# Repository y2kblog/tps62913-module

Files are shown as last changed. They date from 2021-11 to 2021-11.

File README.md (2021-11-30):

# TPS62913 低ノイズ・低リップル 可変出力降圧モジュール

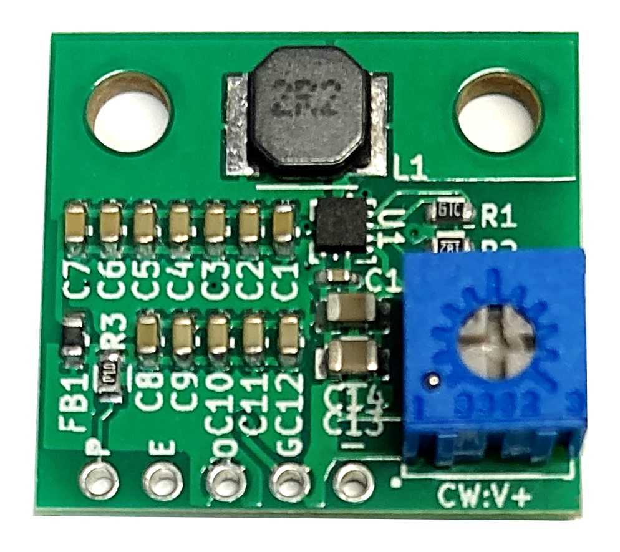
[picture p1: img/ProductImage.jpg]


## 概要

低ノイズ・低リップルの降圧型DC/DCコンバータ TPS62913 (Texas Instruments Inc.製) を搭載したモジュールです。  
低ノイズLDOに匹敵する**20µV<sub>RMS</sub>の1/fノイズ**と、IC内蔵のフェライトビーズLCフィルタ補償機能による**10µV<sub>RMS</sub>未満の低リップル**を実現しており、ノイズの影響を受けやすいアプリケーション（例：実験用精密電源、高速ADC、レーダー）の電源供給に適しています。  
また、スイッチングレギュレータのため最大3.0Aの電流を出力できます。  

### 仕様
- 入力電圧：3.0～17.0V
- 出力電圧：0.9～5.1V (基板上の半固定抵抗で調整)
- 最大出力電流：3.0A
- 1/fノイズ：20µV<sub>RMS</sub> (100Hz～100kHz)
- 電圧リップル：10µV<sub>RMS</sub>未満 (typ.)
- イネーブルピン付き
- パワー・グッドピン付き
- 出力放電機能：有効
- ソフトスタート時間：10.7ms (typ.)
- 基板サイズ：20mm × 22mm
- ピン間隔：2.54mm
<!--
- スイッチング周波数：2.2MHz (typ.)
- スペクトラム拡散変調：有効
-->

## 販売  
[スイッチサイエンス委託販売ページ](https://www.switch-science.com/catalog/7619/)  
※大量注文や在庫に関する問い合わせは[こちら](mailto:info.y2kb@gmail.com)までご連絡ください。  

## ピンアサイン
<table>
    <thead>
        <tr>
            <th>#</th>
            <th>ピン名</th>
            <th>表面シルク</th>
            <th>説明</th>
        </tr>
    </thead>
    <tbody>
        <tr>
            <td>1</td>
            <td>VIN</td>
            <td>I</td>
            <td>電源入力</td>
        </tr>
        <tr>
            <td>2</td>
            <td>GND</td>
            <td>G</td>
            <td>グラウンド（基準電位）</td>
        </tr>
        <tr>
            <td>3</td>
            <td>VOUT</td>
            <td>O</td>
            <td>電源出力</td>
        </tr>
        <tr>
            <td>4</td>
            <td>EN</td>
            <td>E</td>
            <td>イネーブル<br>デフォルトではENピンはVINピンに基板内部で接続されており、常時出力ONです。基板裏面のJP1ショートジャンパをカッター等で切断するとENピンによる出力ON/OFF制御が可能になり、ENピンに約1V以上を印加すると出力がONになります。</td>
        </tr>
        <tr>
            <td>5</td>
            <td>PG</td>
            <td>P</td>
            <td>パワー・グッド<br>VOUTがパワー・グッド閾値電圧を下回るとGNDと同等の電圧となります。出力電圧が良好な場合はVOUTと同等の電圧となります。</td>
        </tr>
    </tbody>
</table>

## 回路図  
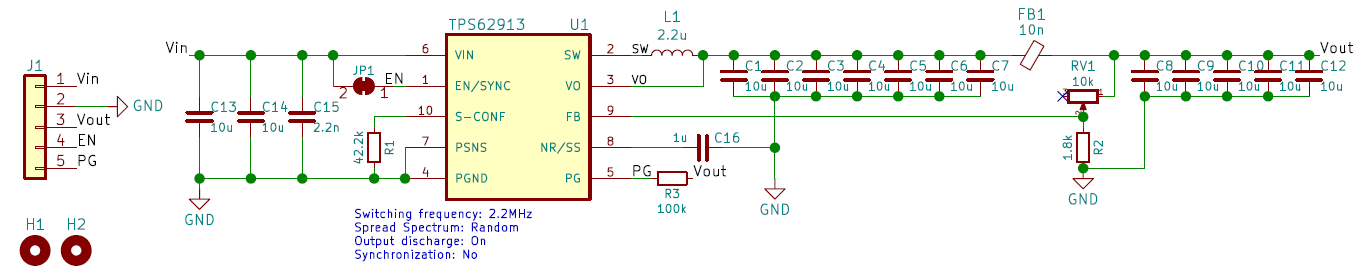
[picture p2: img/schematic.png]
  

<!--<a href="/hardware/tps62913-module.pdf">回路図(PDF)</a>  -->

## 基板寸法
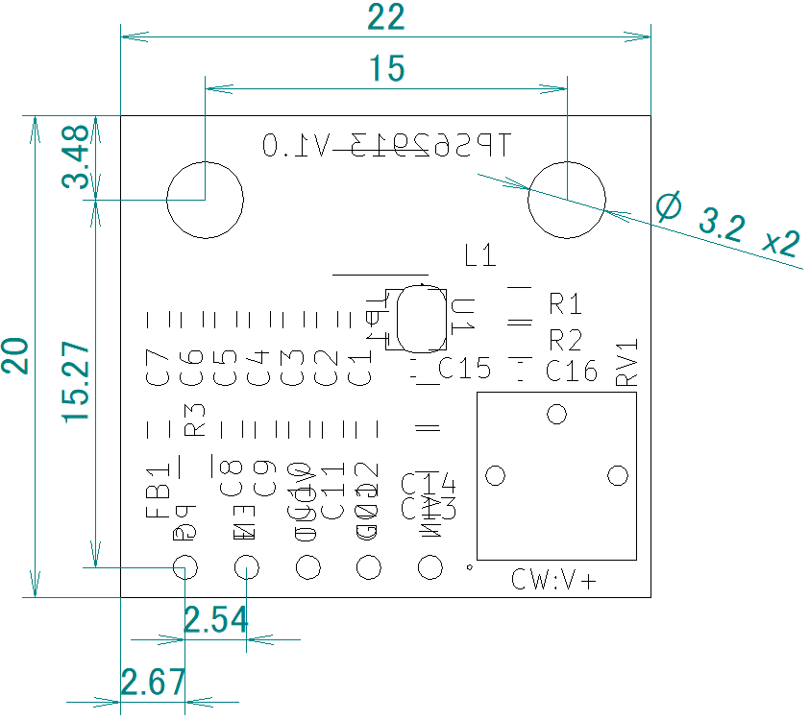
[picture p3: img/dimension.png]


## 資料
- 2Dデータ(DXF)：<a href="https://github.com/y2kblog/tps62913-module/raw/master/hardware/dxf/tps62913-module_dxf.zip" download="">tps62913-module_dxf.zip</a>  
- 3Dデータ(STEP)：<a href="https://github.com/y2kblog/tps62913-module/raw/master/hardware/step/tps62913-module_step.zip" download="">tps62913-module_step.zip</a>  
- [TPS61099xデータシート](https://www.tij.co.jp/lit/gpn/tps62913)

## License
MIT License, see `/LICENSE`.

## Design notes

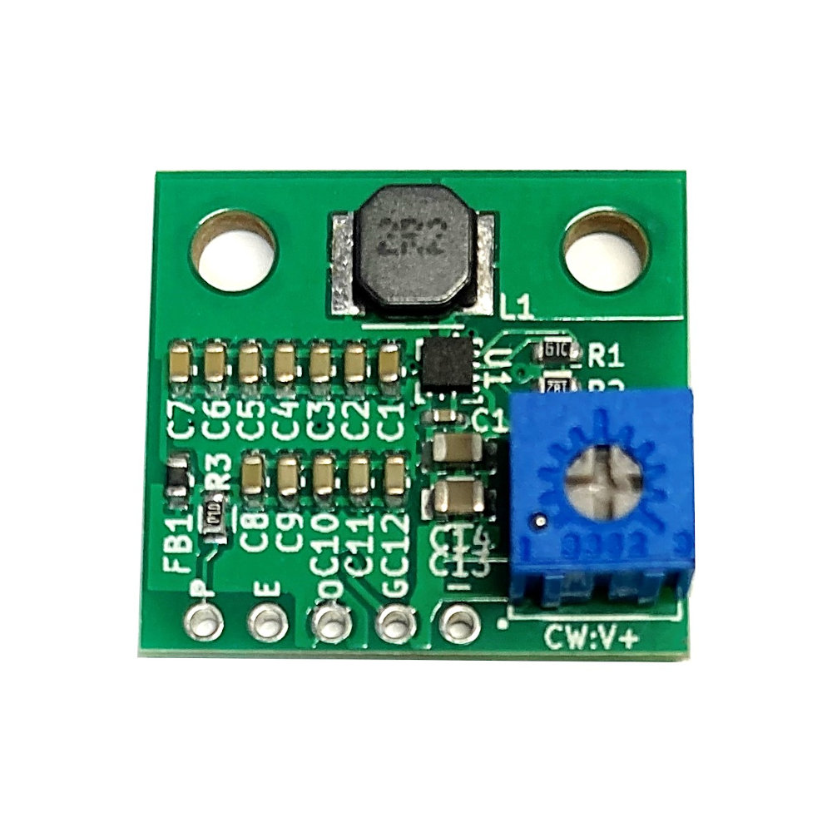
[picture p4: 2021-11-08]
img/ProductImage_1000px.jpg

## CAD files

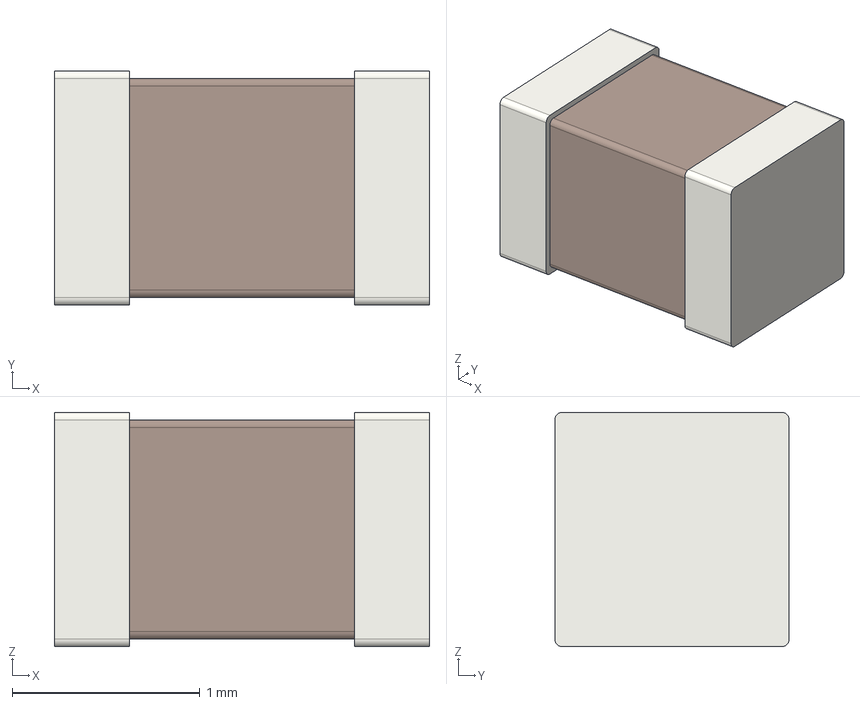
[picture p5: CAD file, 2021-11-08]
hardware/3d/C_0805_2012Metric.step
2.00 x 1.25 x 1.25 mm

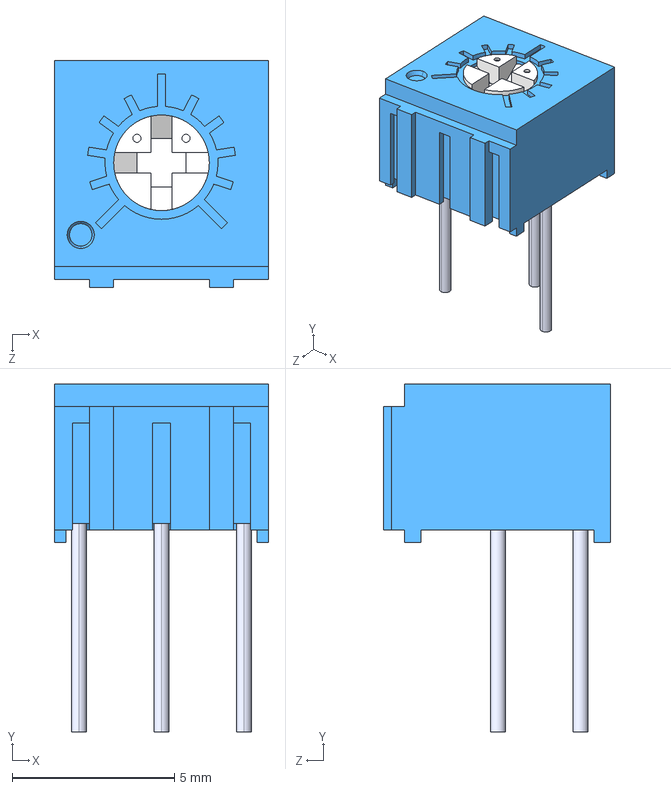
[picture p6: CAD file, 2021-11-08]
hardware/3d/3362P-1.STEP
6.60 x 10.7 x 6.99 mm

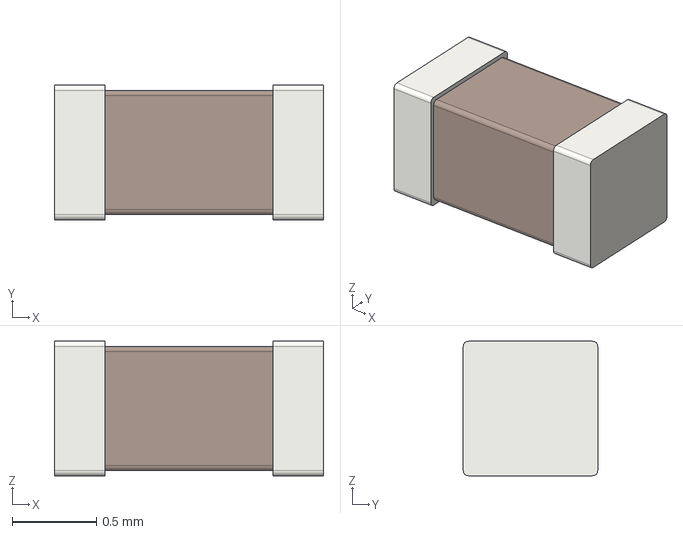
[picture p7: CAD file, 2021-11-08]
hardware/3d/C_0603_1608Metric.step
1.60 x 0.8 x 0.8 mm

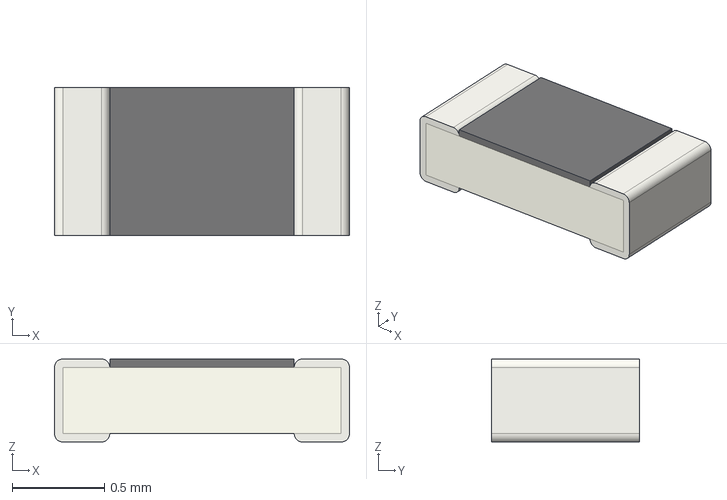
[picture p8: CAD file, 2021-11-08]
hardware/3d/R_0603_1608Metric.step
1.60 x 0.8 x 0.45 mm

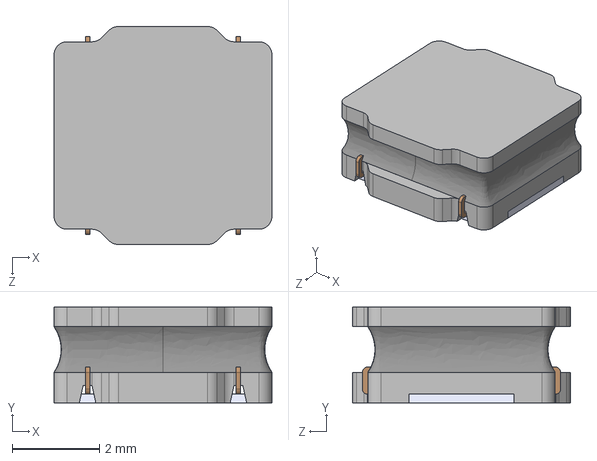
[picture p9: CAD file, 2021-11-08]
hardware/3d/inductor_5x5.STEP
5.00 x 2.20 x 5.00 mm

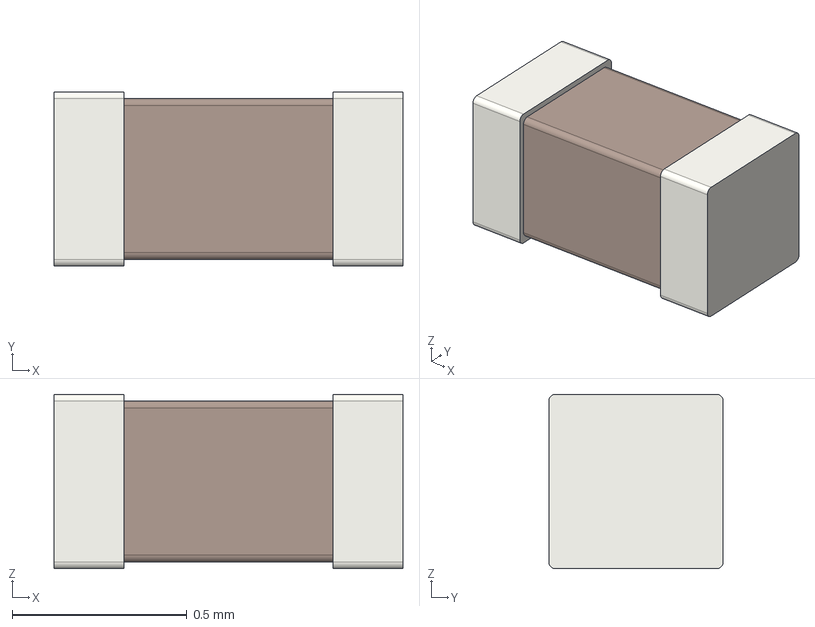
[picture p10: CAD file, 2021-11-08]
hardware/3d/C_0402_1005Metric.step
1.00 x 0.5 x 0.5 mm

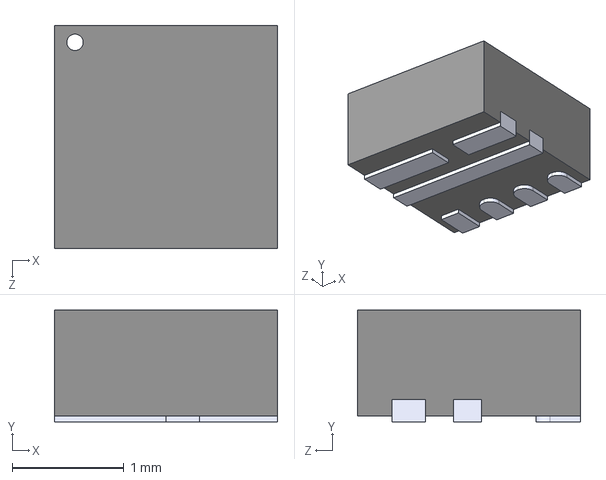
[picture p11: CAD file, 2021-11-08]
hardware/3d/7-VQFN-HR.STEP
2.00 x 1.00 x 2.00 mm

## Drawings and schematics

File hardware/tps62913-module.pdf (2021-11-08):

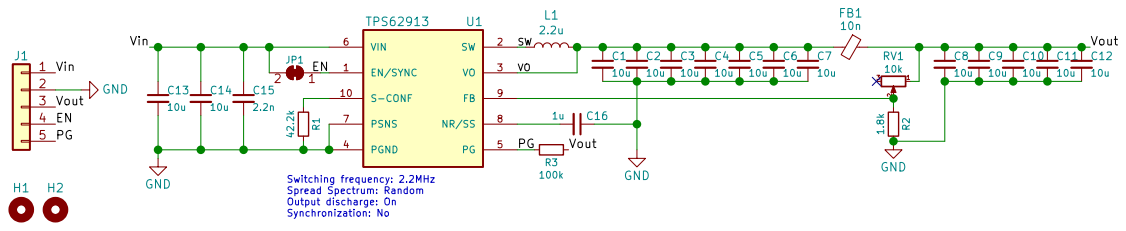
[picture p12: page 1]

Output discharge: On Synchronization: No

File: tps62913-module.sch Sheet: /
Id: 1/1 Title: TPS62913 Module

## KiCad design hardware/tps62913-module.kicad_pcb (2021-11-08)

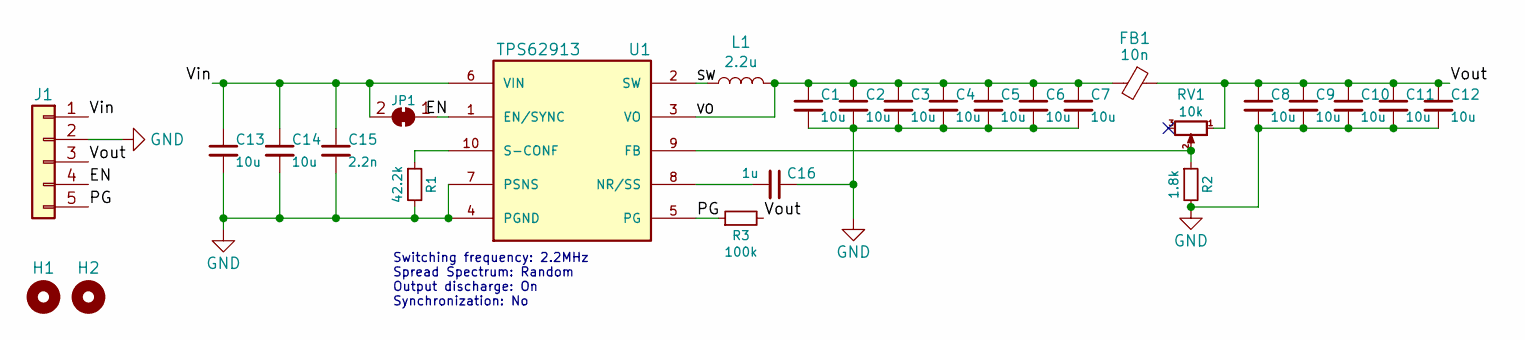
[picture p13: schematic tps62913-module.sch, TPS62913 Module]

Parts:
C1, C2, C3, C4, C5, C6, C7, C8, C9, C10, C11, C12: 10u; C_0603; Rating >=10V
C13, C14: 10u; C_0805
C15: 2.2n; C_0402; Rating >=25V
C16: 1u; C_0402
FB1: 10n; C_0603
H1, H2: MountingHole; MountingHole_3.2mm_M3
J1: Conn_01x05; SIL-5
JP1: SolderJumper_2_Bridged; SolderJumper-2_P1.3mm_Bridged_RoundedPad1.0x1.5mm
L1: 2.2u; SWPA-2020
R1: 42.2k; R_0603
R2: 1.8k; R_0603
R3: 100k; R_0603
RV1: 10k; VR_3362P-1
U1: TPS62913; TPS6291x; Digikey # 296-TPS62913RPURCT-ND

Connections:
/EN: J1.4, JP1.1 (A), U1.1 (EN/SYNC)
/PG: J1.5, R3.1, U1.5 (PG)
/SW: L1.1, U1.2 (SW)
/VO: C1.1, C2.1, C3.1, C4.1, C5.1, C6.1, C7.1, FB1.2, L1.2, U1.3 (VO)
/Vin: C13.1, C14.1, C15.1, J1.1, JP1.2 (B), U1.6 (VIN)
/Vout: C8.1, C9.1, C10.1, C11.1, C12.1, FB1.1, J1.3, R3.2, RV1.1
GND: C1.2, C2.2, C3.2, C4.2, C5.2, C6.2, C7.2, C8.2, C9.2, C10.2, C11.2, C12.2, C13.2, C14.2, C15.2, C16.1, J1.2, R1.2, R2.2, U1.4 (PGND), U1.7 (PSNS)
unnamed: C16.2, U1.8 (NR/SS)
unnamed: R1.1, U1.10 (S-CONF)
unnamed: R2.1, RV1.2, U1.9 (FB)

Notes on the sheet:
Switching frequency: 2.2MHz Spread Spectrum: Random Output discharge: On Synchronization: No

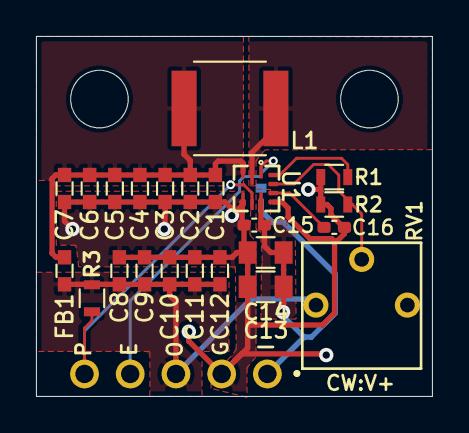
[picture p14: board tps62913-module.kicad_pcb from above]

Board: 2 copper layers, 22.0 x 20.0 mm, 27 parts (1 on the bottom side), 10 nets.

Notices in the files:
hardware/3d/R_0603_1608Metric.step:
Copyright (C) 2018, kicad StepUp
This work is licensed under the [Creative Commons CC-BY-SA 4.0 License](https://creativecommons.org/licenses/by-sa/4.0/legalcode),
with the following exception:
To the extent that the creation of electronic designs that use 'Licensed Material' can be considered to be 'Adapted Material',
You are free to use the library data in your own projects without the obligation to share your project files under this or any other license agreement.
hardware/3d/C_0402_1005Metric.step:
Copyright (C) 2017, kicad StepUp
